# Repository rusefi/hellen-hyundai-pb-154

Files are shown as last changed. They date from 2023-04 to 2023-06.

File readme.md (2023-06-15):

https://en.wikipedia.org/wiki/Hyundai-Kia_small_automobile_platforms

https://rusefi.com/docs/pinouts/hellen/hellen-hyundai-pb-mt/

same pinout for

2012-2017 Hyundai Accent

2012-2017 Kia Rio

2012-2017 Kia Soul 1.6

2013-2017 Hyundai Veloster 1.6 Turbo

2014-2017 Kia Forte 1.6 Turbo

https://github.com/rusefi/rusefi_documentation/tree/master/OEM-Docs/Kia

https://github.com/rusefi/rusefi_documentation/blob/master/OEM-Docs/Kia/2014-soul.pdf

https://github.com/rusefi/rusefi_documentation/blob/master/OEM-Docs/Kia/2015-koup.pdf?

https://github.com/rusefi/rusefi_documentation/tree/master/OEM-Docs/Hyundai

https://github.com/rusefi/rusefi_documentation/blob/master/OEM-Docs/Hyundai/2014-veloster.pdf ?

Not to be confused with MEFI https://github.com/rusefi/hellen154hyundai

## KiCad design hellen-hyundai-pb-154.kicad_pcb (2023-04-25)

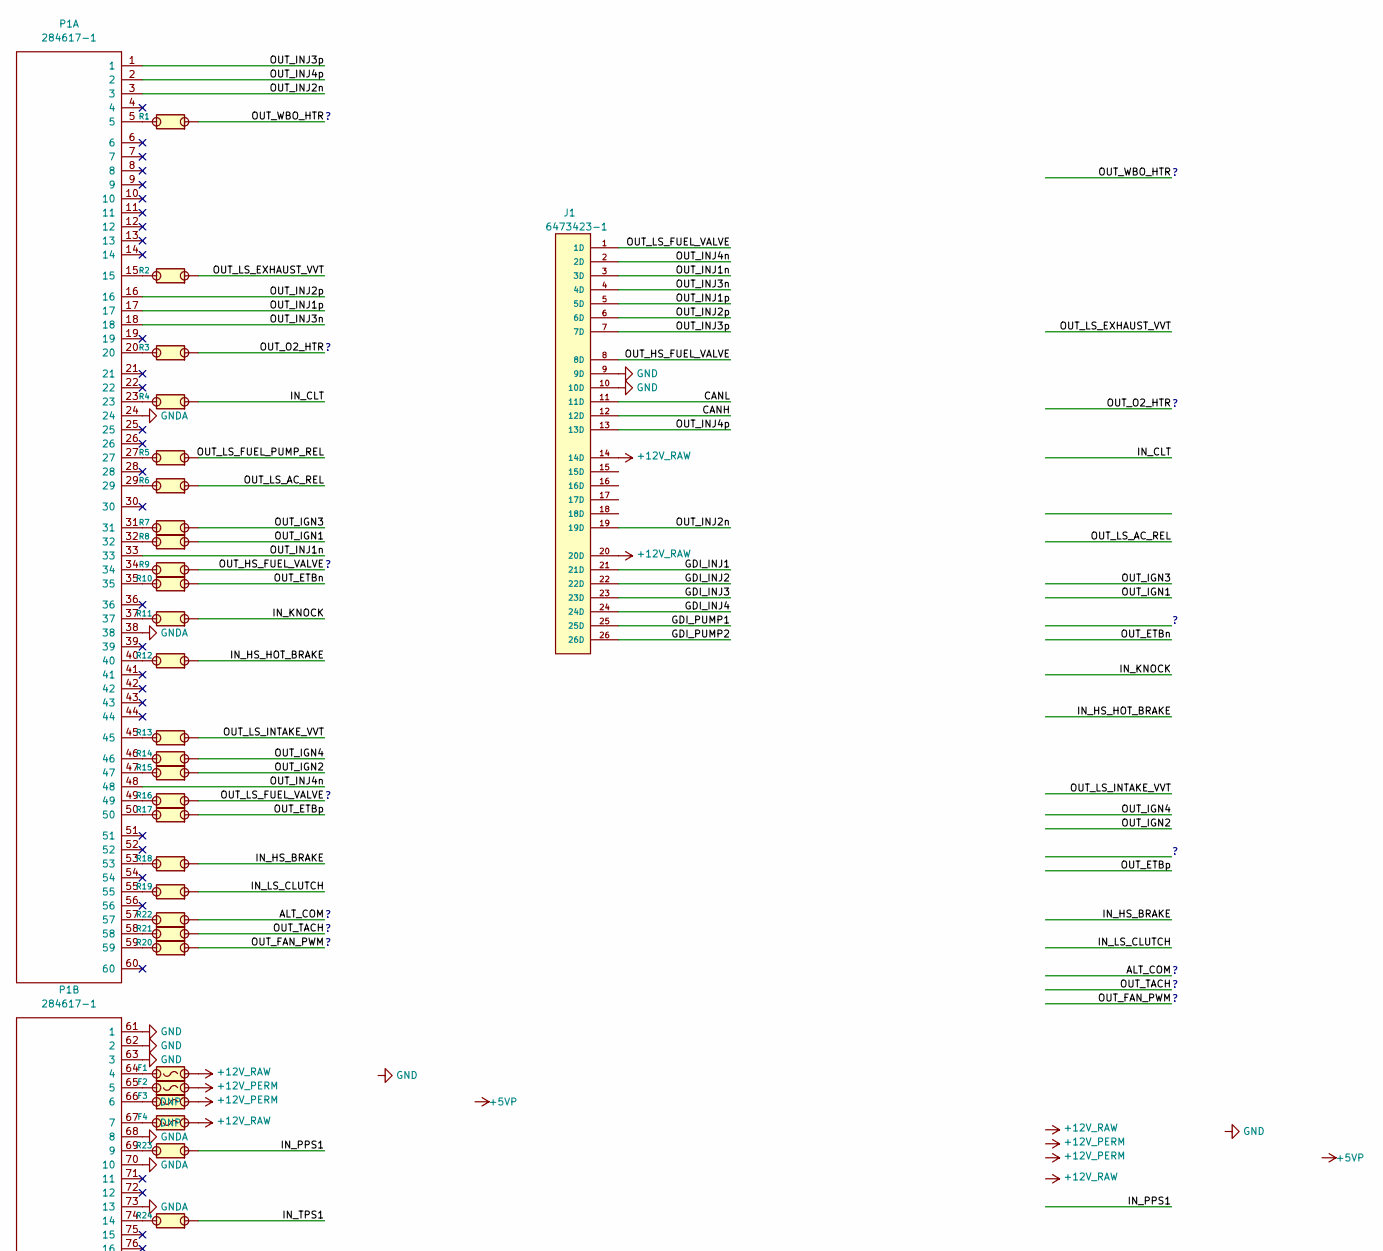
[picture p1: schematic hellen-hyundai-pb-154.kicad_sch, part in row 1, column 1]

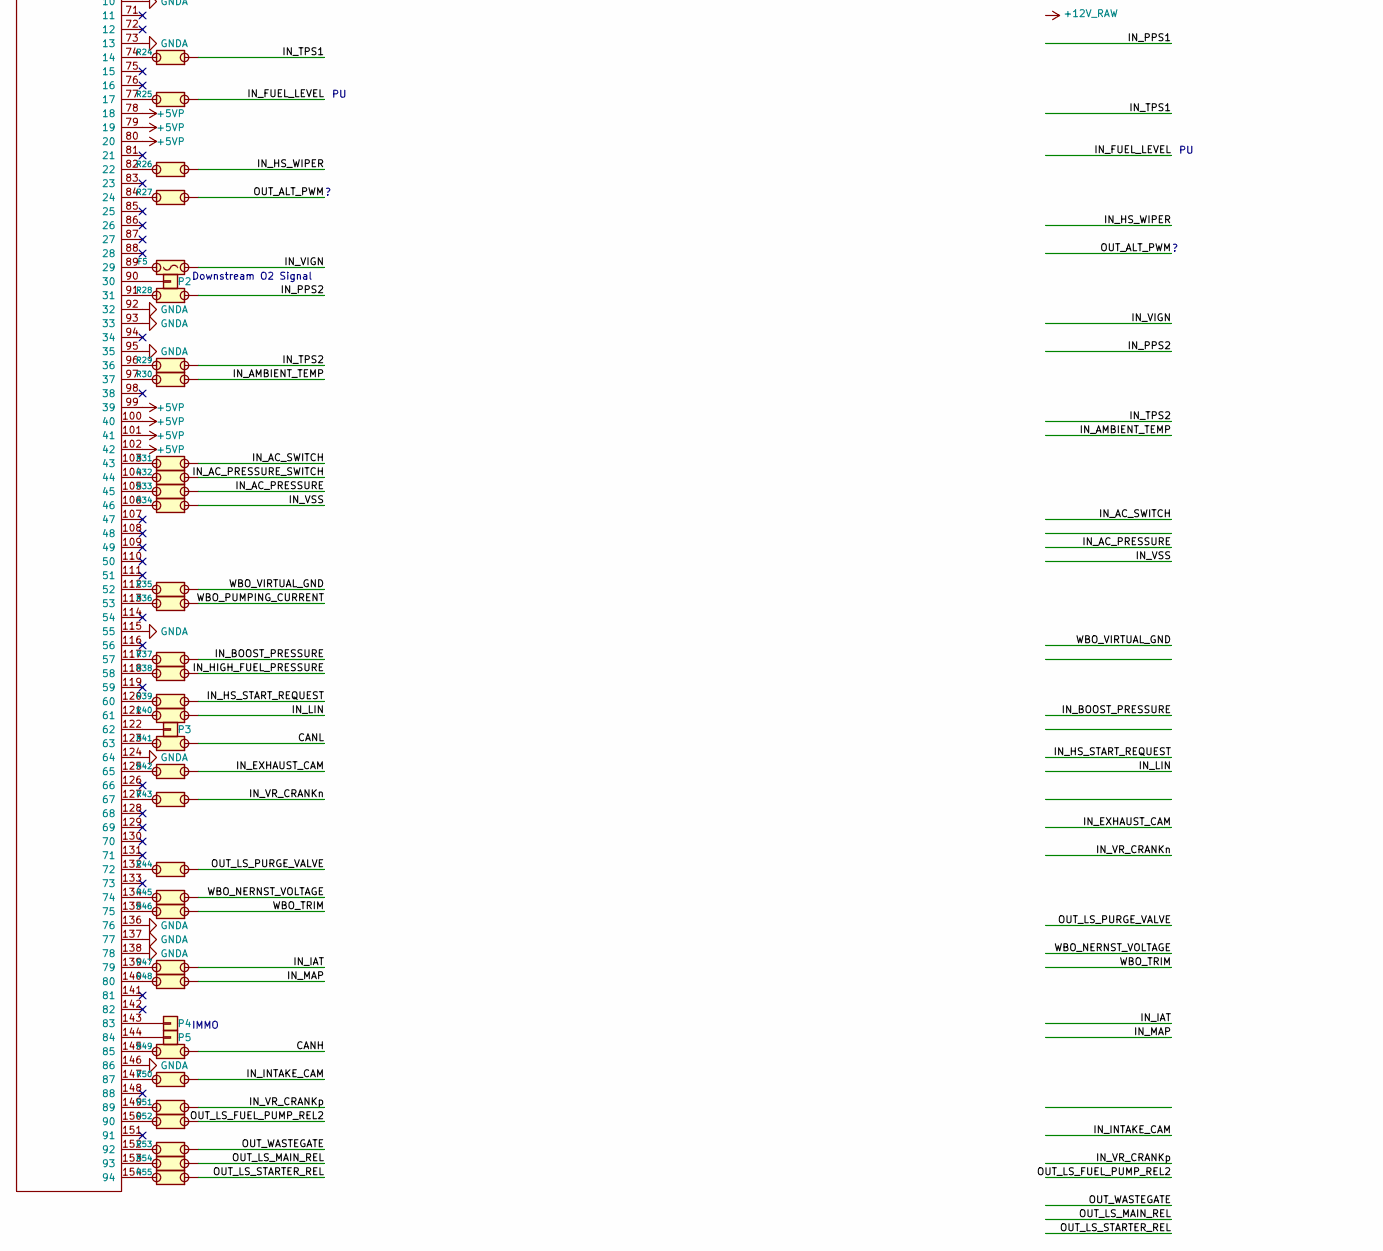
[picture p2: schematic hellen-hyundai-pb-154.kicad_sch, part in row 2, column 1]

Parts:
F1, F2, F5: Fuse-Pad-Pad; PAD-1206-PAD; LCSC C182446
F3, F4: Fuse-Pad-Pad; PAD-1206-PAD
J1: 6473423-1
P1: 284617-1; TE_284617-1
P2, P3, P4, P5: Pad; PAD-TH
R1, R2, R3, R4, R5, R6, R7, R8, R9, R10, R11, R12, R13, R14, R15, R16, R17, R18, R19, R20, R21, R22, R23, R24, R25, R26, R27, R28, R29, R30, R31, R32, R33, R34, R35, R36, R37, R38, R39, R40, R41, R42, R43, R44, R45, R46, R47, R48, R49, R50, R51, R52, R53, R54, R55: Jumper-Pad-Pad; PAD-0805-PAD; LCSC C17477

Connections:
+5VP: P1.78 (18), P1.79 (19), P1.80 (20), P1.99 (39), P1.100 (40), P1.101 (41), P1.102 (42)
+12V_PERM: F2.2, F3.2
+12V_RAW: F1.2, F4.2, J1.14 (14D), J1.20 (20D)
/ALT_COM: R22.1
/CANH: J1.12 (12D), R49.1
/CANL: J1.11 (11D), R41.1
/GDI_INJ1: J1.21 (21D)
/GDI_INJ2: J1.22 (22D)
/GDI_INJ3: J1.23 (23D)
/GDI_INJ4: J1.24 (24D)
/GDI_PUMP1: J1.25 (25D)
/GDI_PUMP2: J1.26 (26D)
/IN_AC_PRESSURE: R33.1
/IN_AC_PRESSURE_SWITCH: R32.1
/IN_AC_SWITCH: R31.1
/IN_AMBIENT_TEMP: R30.1
/IN_BOOST_PRESSURE: R37.1
/IN_CLT: R4.1
/IN_EXHAUST_CAM: R42.1
/IN_FUEL_LEVEL: R25.1
/IN_HIGH_FUEL_PRESSURE: R38.1
/IN_HS_BRAKE: R18.1
/IN_HS_HOT_BRAKE: R12.1
/IN_HS_START_REQUEST: R39.1
/IN_HS_WIPER: R26.1
/IN_IAT: R47.1
/IN_INTAKE_CAM: R50.1
/IN_KNOCK: R11.1
/IN_LIN: R40.1
/IN_LS_CLUTCH: R19.1
/IN_MAP: R48.1
/IN_PPS1: R23.1
/IN_PPS2: R28.1
/IN_TPS1: R24.1
/IN_TPS2: R29.1
/IN_VIGN: F5.2
/IN_VR_CRANKn: R43.1
/IN_VR_CRANKp: R51.1
/IN_VSS: R34.1
/OUT_ALT_PWM: R27.1
/OUT_ETBn: R10.1
/OUT_ETBp: R17.1
/OUT_FAN_PWM: R20.1
/OUT_HS_FUEL_VALVE: J1.8 (8D), R9.1
/OUT_IGN1: R8.1
/OUT_IGN2: R15.1
/OUT_IGN3: R7.1
/OUT_IGN4: R14.1
/OUT_INJ1n: J1.3 (3D), P1.33
/OUT_INJ1p: J1.5 (5D), P1.17
/OUT_INJ2n: J1.19 (19D), P1.3
/OUT_INJ2p: J1.6 (6D), P1.16
/OUT_INJ3n: J1.4 (4D), P1.18
/OUT_INJ3p: J1.7 (7D), P1.1
/OUT_INJ4n: J1.2 (2D), P1.48
/OUT_INJ4p: J1.13 (13D), P1.2
/OUT_LS_AC_REL: R6.1
/OUT_LS_EXHAUST_VVT: R2.1
/OUT_LS_FUEL_PUMP_REL: R5.1
/OUT_LS_FUEL_PUMP_REL2: R52.1
/OUT_LS_FUEL_VALVE: J1.1 (1D), R16.1
/OUT_LS_INTAKE_VVT: R13.1
/OUT_LS_MAIN_REL: R54.1
/OUT_LS_PURGE_VALVE: R44.1
/OUT_LS_STARTER_REL: R55.1
/OUT_O2_HTR: R3.1
/OUT_TACH: R21.1
/OUT_WASTEGATE: R53.1
/OUT_WBO_HTR: R1.1
/WBO_NERNST_VOLTAGE: R45.1
/WBO_PUMPING_CURRENT: R36.1
/WBO_TRIM: R46.1
/WBO_VIRTUAL_GND: R35.1
GND: J1.9 (9D), J1.10 (10D), P1.61 (1), P1.62 (2), P1.63 (3)
GNDA: P1.24, P1.38, P1.68 (8), P1.70 (10), P1.73 (13), P1.92 (32), P1.93 (33), P1.95 (35), P1.115 (55), P1.124 (64), P1.136 (76), P1.137 (77), P1.138 (78), P1.146 (86)
unnamed: P1.5, R1.2
unnamed: P1.15, R2.2
unnamed: P1.20, R3.2
unnamed: P1.23, R4.2
unnamed: P1.27, R5.2
unnamed: P1.29, R6.2
unnamed: P1.31, R7.2
unnamed: P1.32, R8.2
unnamed: P1.34, R9.2
unnamed: P1.35, R10.2
unnamed: P1.37, R11.2
unnamed: P1.40, R12.2
unnamed: P1.45, R13.2
unnamed: P1.46, R14.2
unnamed: P1.47, R15.2
unnamed: P1.49, R16.2
unnamed: P1.50, R17.2
unnamed: P1.53, R18.2
unnamed: P1.55, R19.2
unnamed: P1.57, R22.2
unnamed: P1.58, R21.2
unnamed: P1.59, R20.2
unnamed: F1.1, P1.64 (4)
unnamed: F2.1, P1.65 (5)
unnamed: F3.1, P1.66 (6)
unnamed: F4.1, P1.67 (7)
unnamed: P1.69 (9), R23.2
unnamed: P1.74 (14), R24.2
unnamed: P1.77 (17), R25.2
unnamed: P1.82 (22), R26.2
unnamed: P1.84 (24), R27.2
unnamed: F5.1, P1.89 (29)
unnamed: P1.90 (30), P2.1
unnamed: P1.91 (31), R28.2
unnamed: P1.96 (36), R29.2
unnamed: P1.97 (37), R30.2
unnamed: P1.103 (43), R31.2
unnamed: P1.104 (44), R32.2
unnamed: P1.105 (45), R33.2
unnamed: P1.106 (46), R34.2
unnamed: P1.112 (52), R35.2
unnamed: P1.113 (53), R36.2
unnamed: P1.117 (57), R37.2
unnamed: P1.118 (58), R38.2
unnamed: P1.120 (60), R39.2
unnamed: P1.121 (61), R40.2
unnamed: P1.122 (62), P3.1
unnamed: P1.123 (63), R41.2
unnamed: P1.125 (65), R42.2
unnamed: P1.127 (67), R43.2
unnamed: P1.132 (72), R44.2
unnamed: P1.134 (74), R45.2
unnamed: P1.135 (75), R46.2
unnamed: P1.139 (79), R47.2
unnamed: P1.140 (80), R48.2
unnamed: P1.143 (83), P4.1
unnamed: P1.144 (84), P5.1
unnamed: P1.145 (85), R49.2
unnamed: P1.147 (87), R50.2
unnamed: P1.149 (89), R51.2
unnamed: P1.150 (90), R52.2
unnamed: P1.152 (92), R53.2
unnamed: P1.153 (93), R54.2
unnamed: P1.154 (94), R55.2

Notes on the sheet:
Downstream O2 Signal
IMMO

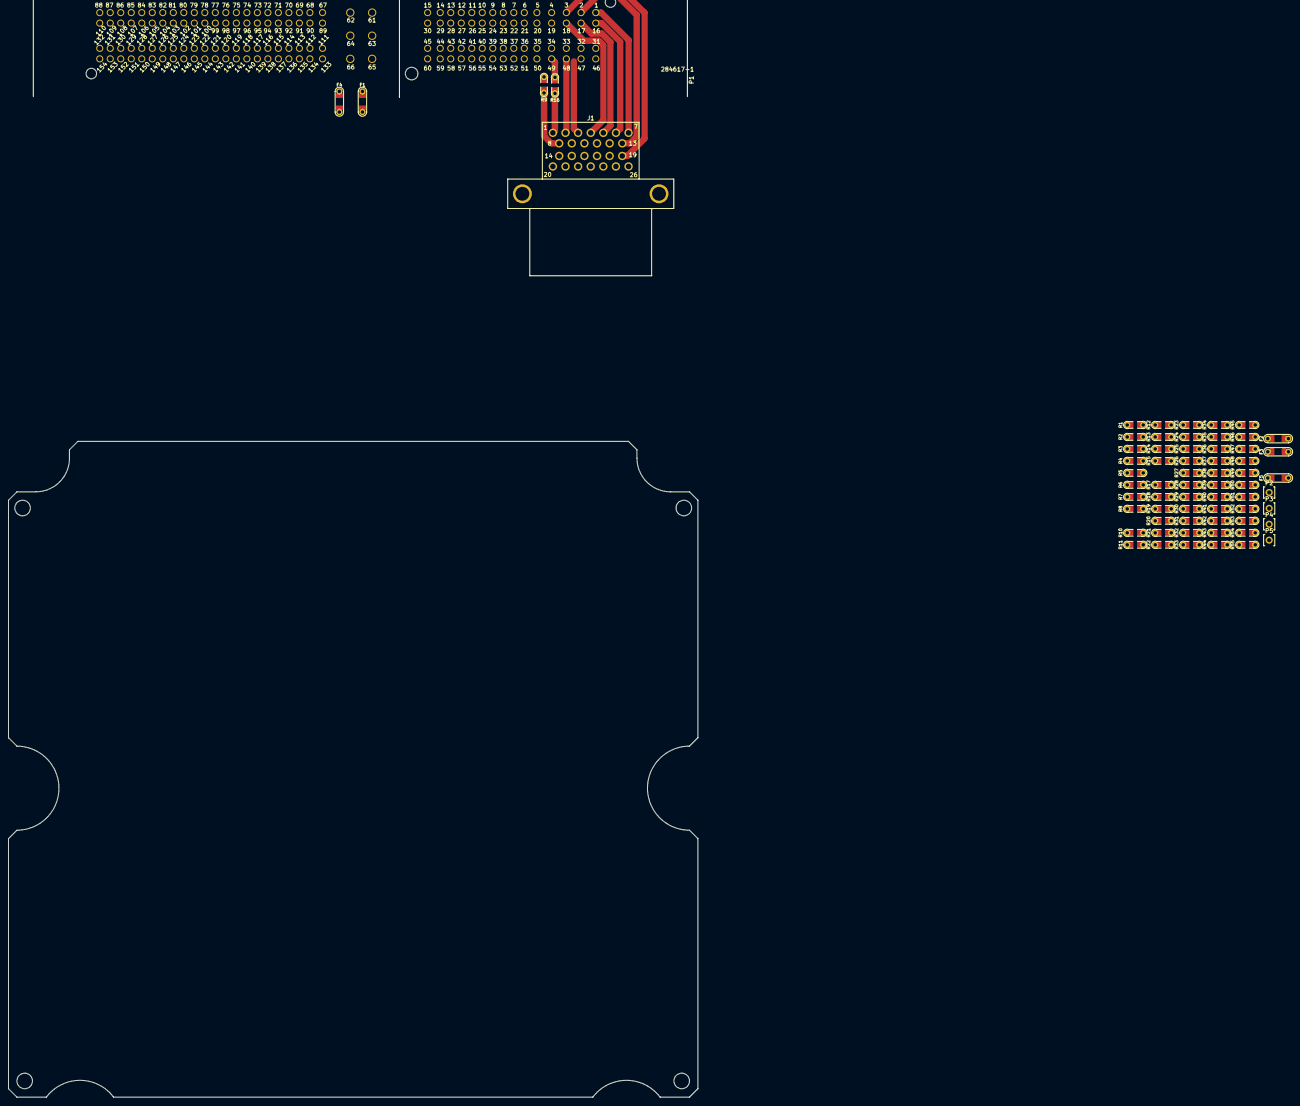
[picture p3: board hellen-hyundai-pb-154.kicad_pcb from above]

Board: 4 copper layers, 164.0 x 156.0 mm, 66 parts (0 on the bottom side), 81 nets.

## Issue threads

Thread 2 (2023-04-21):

failing to read start request with Proteus

rusefillc, 2023-04-21:
https://rusefi.com/docs/pinouts/hellen/hellen-hyundai-pb-mt/?pin=K60 K60
висящий провод 0в не кручение стартёром, +12 кручаение стартёром

подкоючённо к протеус digital 3 small plug pin 2 так же 0в не кручение стартёром, +12 кручаение стартёром
https://rusefi.com/docs/pinouts/proteus/?connector=black23&pin=2

```
2023-04-21_14_00_57_047: EngineState: pin Digital 3 value 1
2023-04-21_14_00_57_048: EngineState: confirmation_readpin pe12:12
2023-04-21_14_00_57_701: EngineState: pin Digital 3 value 1
2023-04-21_14_00_57_702: EngineState: confirmation_readpin pe12:12
2023-04-21_14_00_58_243: EngineState: pin Digital 3 value 1
2023-04-21_14_00_58_244: EngineState: confirmation_readpin pe12:12
2023-04-21_14_00_58_899: EngineState: pin Digital 3 value 1
2023-04-21_14_00_58_900: EngineState: confirmation_readpin pe12:12
2023-04-21_14_00_59_042: EngineState: pin Digital 3 value 1
2023-04-21_14_00_59_042: EngineState: confirmation_readpin pe12:12
2023-04-21_14_00_59_335: EngineState: pin Digital 3 value 1
2023-04-21_14_00_59_336: EngineState: confirmation_readpin pe12:12
2023-04-21_14_00_59_889: EngineState: pin Digital 3 value 1
2023-04-21_14_00_59_890: EngineState: confirmation_readpin pe12:12
```

rusefillc, 2023-04-22:
analog input has worked!

Closed 2023-04-22.

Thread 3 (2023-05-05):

Features

Qwerty-OFF, 2023-05-05:
1. Нужны софтварно-подключаемые 120 Ом CAN?
2. USB: тип B плюс 5 дырок?
3. Батарейка 2032 или маленькая?
4. Что делать с пином 57/60 ALTERNATOR COM?
5. Выход на тахометр 58/60 это LS/HS/PP?
6. Пин 59/60 FAN PWM это что?
7. Пин 24/94 ALTERNATOR PWM?
8. Катушки тупые?

rusefillc, 2023-05-05:
1. нет, без софтварно-подключаемого 120 Ом CAN
2. да, USB: тип B плюс 5 дырок
3. Батарейка маленькая
4.
5.
6.
8. да, катушки глупые

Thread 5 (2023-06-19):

LP Fuel Pump Control confusion

rusefillc, 2023-06-19:
```
  - pin: A27
    ts_name: A27 Fuel Pump Control
    function: LP Fuel Pump Control
```

```
  - pin: K90
    ts_name: K90 Fuel Pump Control
    function: LP Fuel Pump Control
```

rusefillc, 2023-06-19:
CCV is canister close valve, we do not care about it. We are OK with one control line and PCB jumper.

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

Qwerty-OFF, 2023-06-19:
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
https://github.com/rusefi/rusefi_documentation/blob/master/OEM-Docs/Hyundai/2014-veloster.pdf

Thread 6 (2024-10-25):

Gnd pins have no continuity?

ElDominio, 2024-10-25:
Car with pb board had odd power issues, showing high resistance on ground to chassis. Visual inspection showed grounds improperly traced.
Added cables from gnd to gnd pins and the issue was resolved

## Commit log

2023-04-20 Init project
    [hellen-hyundai-pb-154.kicad_pcb, hellen-hyundai-pb-154.kicad_sch]
2023-04-25 GDI pinout
    [hellen-hyundai-pb-154.kicad_pcb, hellen-hyundai-pb-154.kicad_sch]
2023-05-04 Upd SCH
    [ETB.kicad_sch, hellen-hyundai-pb-154.kicad_sch]
2023-06-15 typo - it's dumb
    [DUMB_COILS4.kicad_sch, hellen-hyundai-pb-154.kicad_sch]
